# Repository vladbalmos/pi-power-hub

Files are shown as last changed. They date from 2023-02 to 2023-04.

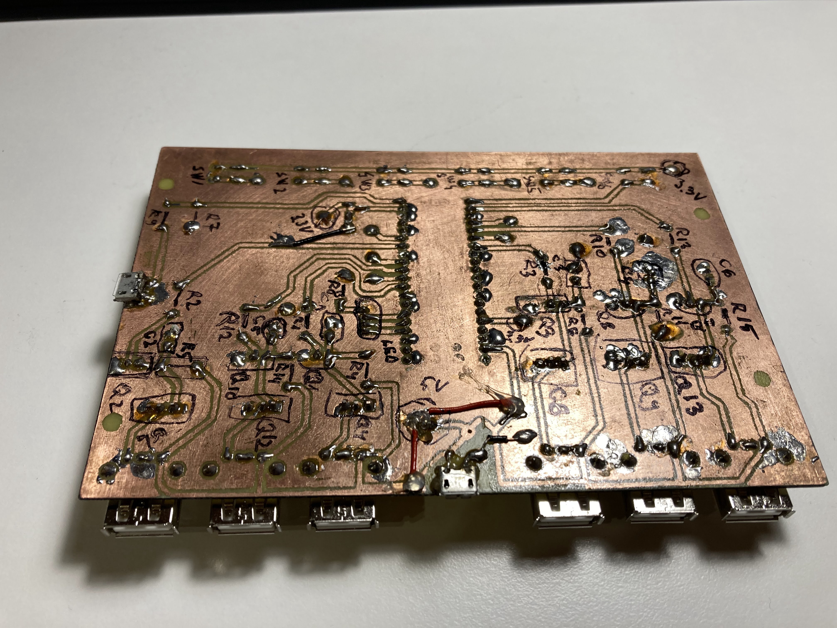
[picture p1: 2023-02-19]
hw/board_back.jpg

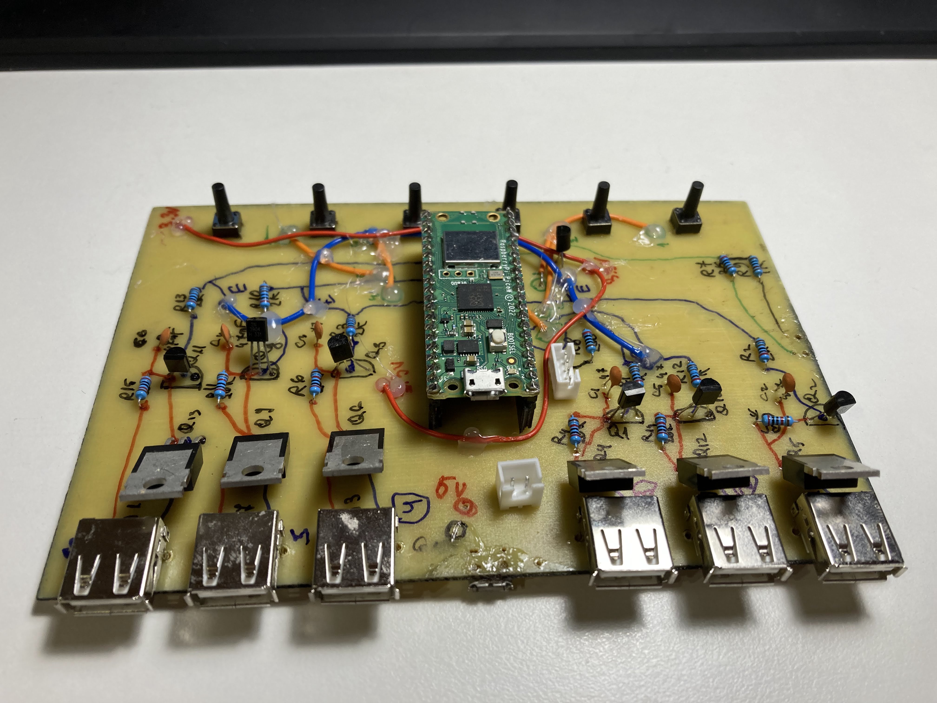
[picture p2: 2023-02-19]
hw/board_front.jpg

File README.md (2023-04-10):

# System requirements
* micropython
* ampy
* minicom (optional)

# Development
Build micropython:

    cd [mycropython-dir]
    make -C mpy-cross

    cd [mycropython-dir]/ports/rp2
    make -j4 BOARD=PICO_W submodules
    make -j4 BOARD=PICO_W clean
    make -j4 BOARD=PICO_W
    
Set wifi SSID & password:

    cp wifi_credentials.template src/wifi_credentials.py
    # edit src/wifi_credentials.py and add SSID & SSID password

Init:

    pip3 install -r requirements.txt
    ./setup.sh
    make build
    
Run:

    make run
    
Clean

    make clean
    
Upload

    make upload
    
Build

    make build

# Topics
* vb/devices/power/pihub/request
    - device subscribes for state change requests
* vb/devices/power/pihub/response
    - device publishes state changes
* vb/devices/request
    - device subscribes for registration requests
* vb/devices/response
    - device publishes device registration data

# Status LED meanings:
* red
    - board initializing
* blue
    - connecting to mqtt server
* green
    - connected to mqtt server
* yellow
    - lost connection to mqtt

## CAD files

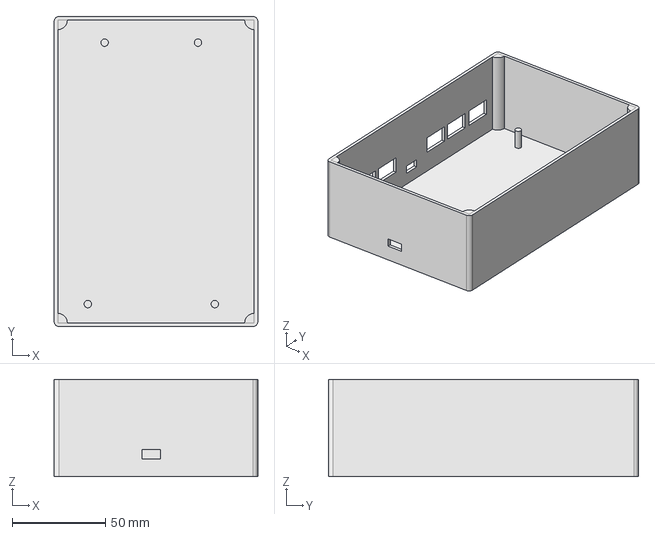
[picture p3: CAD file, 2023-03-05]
hw/enclosure/enclosure.FCStd
109.0 x 166.0 x 52.0 mm

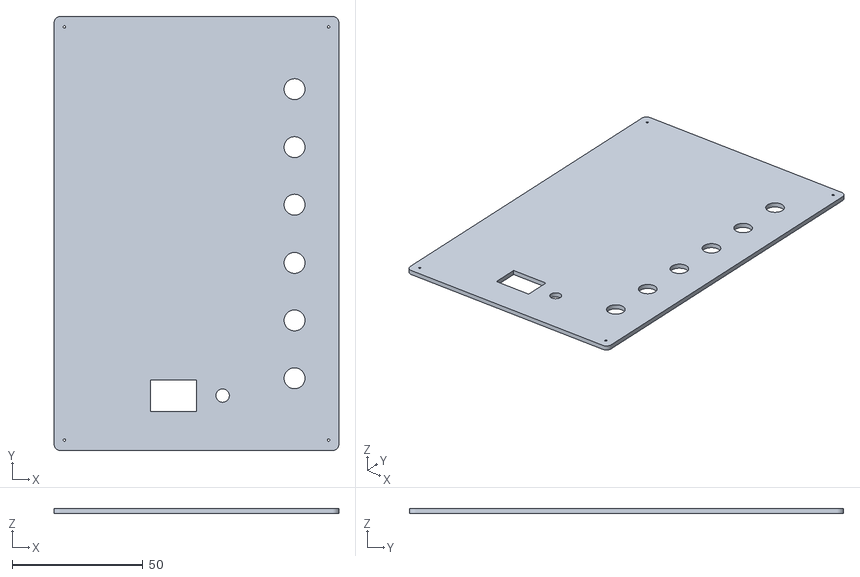
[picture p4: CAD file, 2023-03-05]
hw/enclosure/lid-EnclosureLidBody.stl
109.0 x 166.0 x 2.00

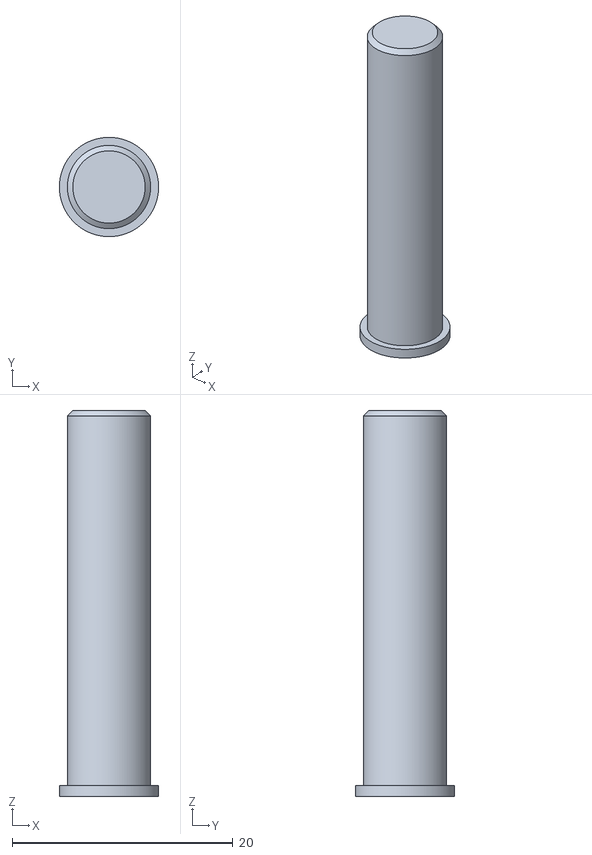
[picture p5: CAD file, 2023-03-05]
hw/enclosure/button-Body.stl
9.00 x 9.00 x 35.0

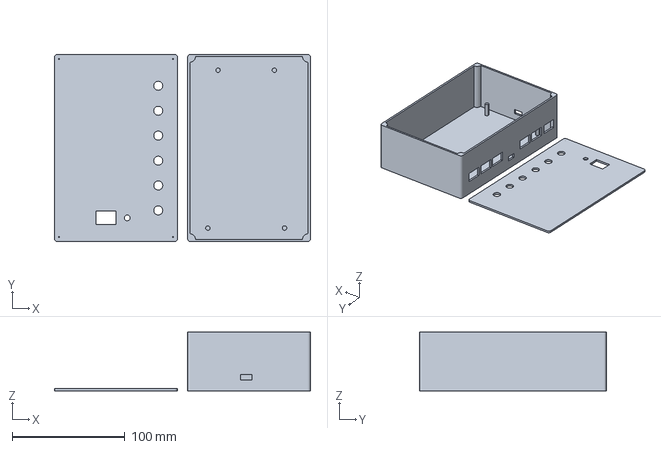
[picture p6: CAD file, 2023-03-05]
hw/enclosure/case.3mf
227.0 x 166.0 x 52.0 mm

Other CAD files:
hw/enclosure/assembled.FCStd
hw/enclosure/body.3mf
hw/enclosure/button.FCStd
hw/enclosure/enclosure-EnclosureBody.stl
hw/enclosure/lid.FCStd
hw/enclosure/button.3mf
hw/enclosure/case.stl
hw/enclosure/lid.3mf

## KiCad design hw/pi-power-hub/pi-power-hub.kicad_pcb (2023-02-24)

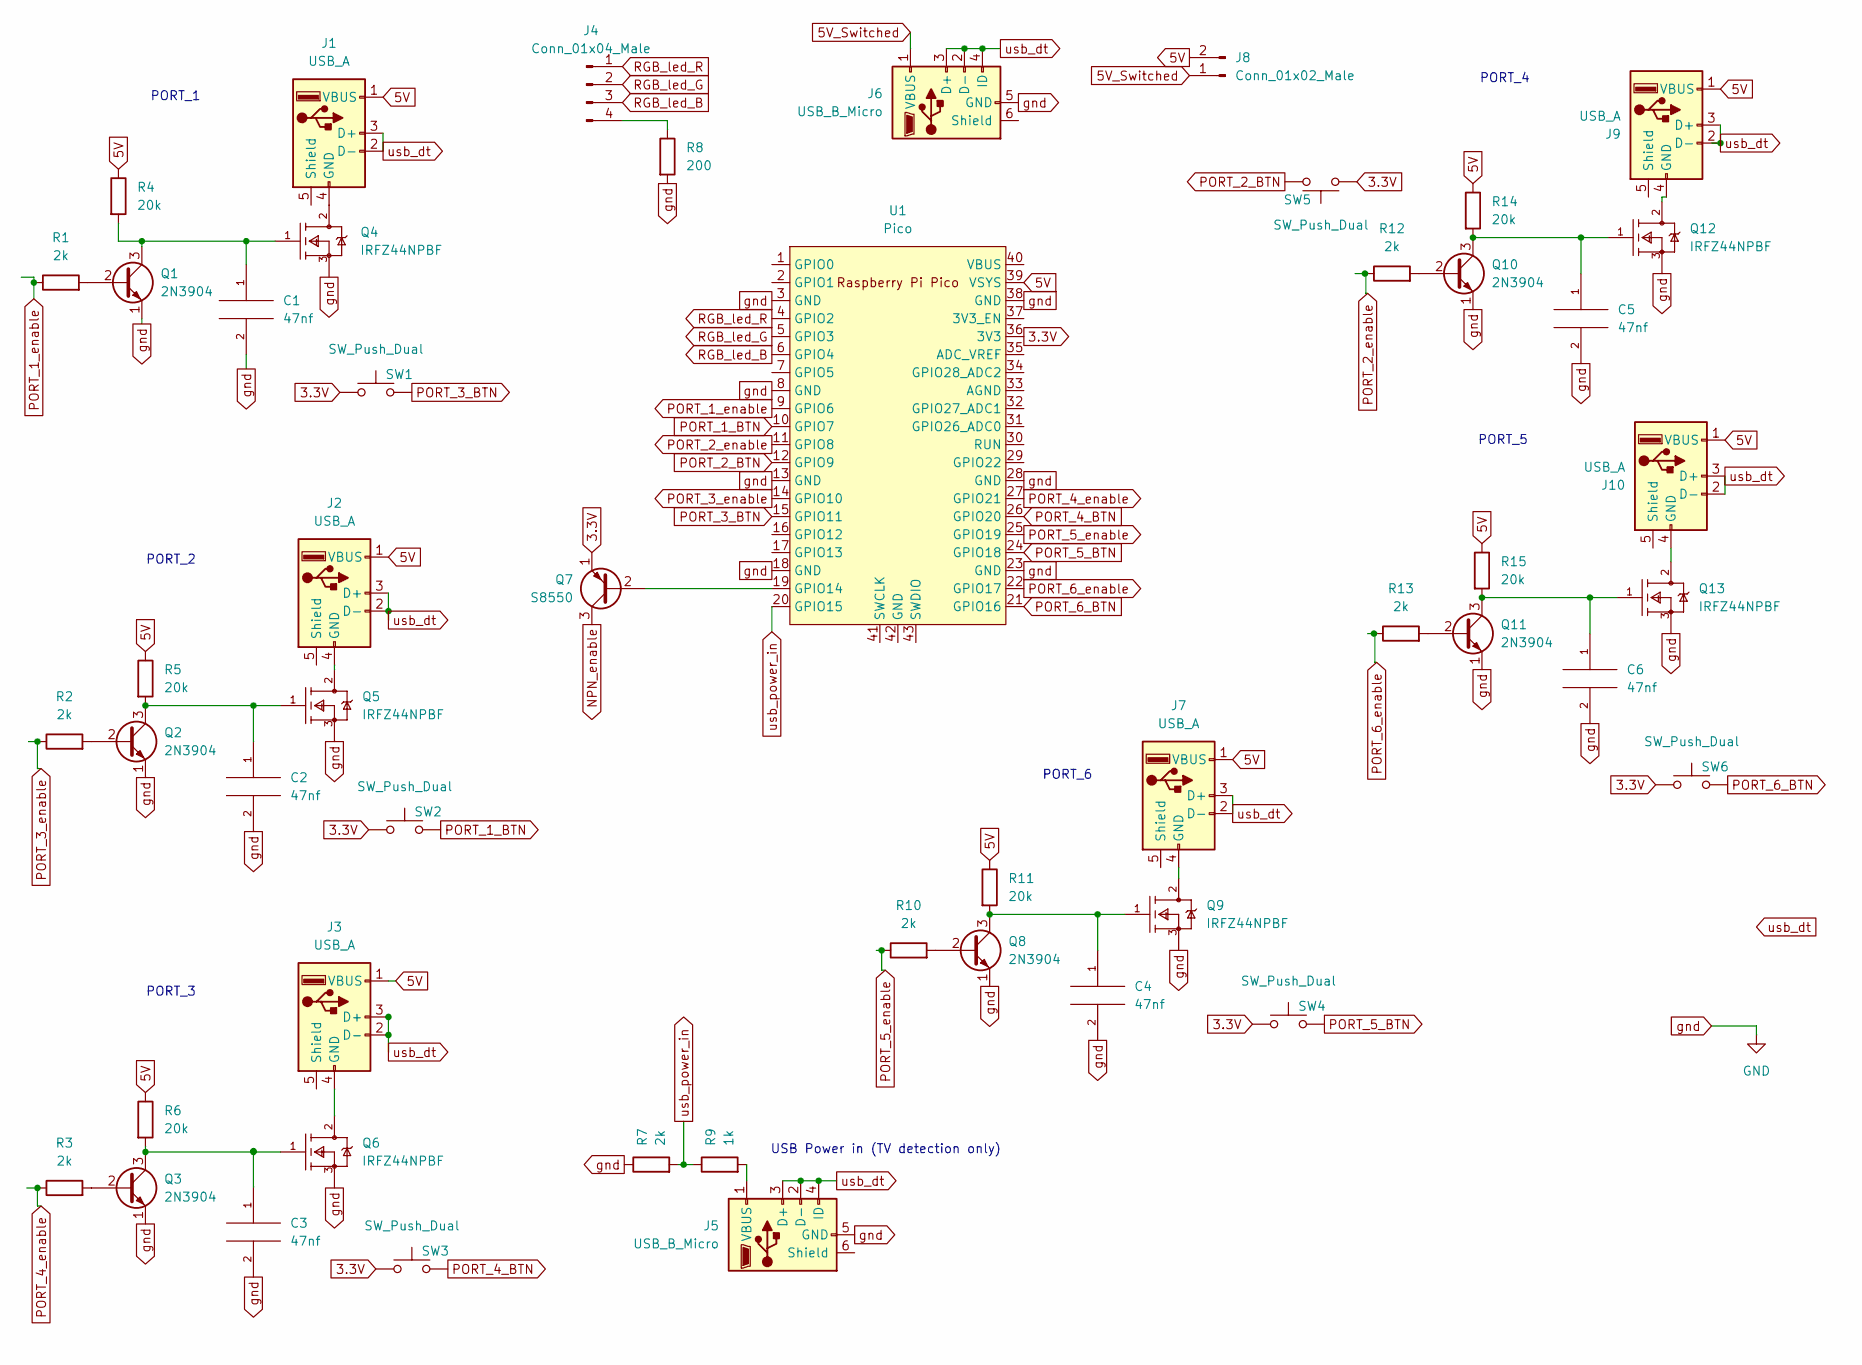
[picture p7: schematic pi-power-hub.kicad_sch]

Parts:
C1, C2, C3, C4, C5, C6: 47nf; C_Disc_D3.8mm_W2.6mm_P2.50mm
J1, J2, J3, J7, J9, J10: USB_A; USB_A_Molex_67643_Horizontal
J4: Conn_01x04_Male; JST_PH_B4B-PH-K_1x04_P2.00mm_Vertical
J5, J6: USB_B_Micro; USB_Micro-B_Amphenol_10103594-0001LF_Horizontal
J8: Conn_01x02_Male; JST_XH_B2B-XH-A_1x02_P2.50mm_Vertical
Q1, Q2, Q3, Q8, Q10, Q11: 2N3904; TO-92_Inline
Q4, Q5, Q6, Q9, Q12, Q13: IRFZ44NPBF; Infineon_Technologies_AG-IRFZ44NPBF-0; mouser part number 942-IRFZ44NPBF; digikey description N-Channel 55V 49A (Tc) 94W (Tc) Through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
Q7: S8550; TO-92_Inline
R1, R2, R3, R7, R10, R12, R13: 2k; R_Axial_DIN0207_L6.3mm_D2.5mm_P7.62mm_Horizontal
R4, R5, R6, R11, R14, R15: 20k; R_Axial_DIN0207_L6.3mm_D2.5mm_P7.62mm_Horizontal
R8: 200; R_Axial_DIN0207_L6.3mm_D2.5mm_P7.62mm_Horizontal
R9: 1k; R_Axial_DIN0207_L6.3mm_D2.5mm_P7.62mm_Horizontal
SW1, SW2, SW3, SW4, SW5, SW6: SW_Push_Dual; SW_PUSH_6mm_H8.5mm
U1: Pico; RPi_Pico_SMD_TH

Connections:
3.3V: Q7.1 (E), SW1.1, SW2.1, SW3.1, SW4.1, SW5.1, SW6.1, U1.36 (3V3)
5V: J1.1 (VBUS), J2.1 (VBUS), J3.1 (VBUS), J7.1 (VBUS), J8.2, J9.1 (VBUS), J10.1 (VBUS), R4.1, R5.1, R6.1, R11.1, R14.1, R15.1, U1.39 (VSYS); also elsewhere on the board
5V_Switched: J6.1 (VBUS), J8.1
NPN_enable: Q7.3 (C)
unnamed: C1.1, Q1.3 (C), Q4.1 (GATE), R4.2
unnamed: C2.1, Q2.3 (C), Q5.1 (GATE), R5.2
unnamed: C3.1, Q3.3 (C), Q6.1 (GATE), R6.2
unnamed: C4.1, Q8.3 (C), Q9.1 (GATE), R11.2
unnamed: C5.1, Q10.3 (C), Q12.1 (GATE), R14.2
unnamed: C6.1, Q11.3 (C), Q13.1 (GATE), R15.2
unnamed: J1.4 (GND), Q4.2 (DRAIN)
unnamed: J2.4 (GND), Q5.2 (DRAIN)
unnamed: J3.4 (GND), Q6.2 (DRAIN)
unnamed: J4.4, R8.1
unnamed: J5.1 (VBUS), R9.2
unnamed: J7.4 (GND), Q9.2 (DRAIN)
unnamed: J9.4 (GND), Q12.2 (DRAIN)
unnamed: J10.4 (GND), Q13.2 (DRAIN)
unnamed: Q1.2 (B), R1.2
unnamed: Q2.2 (B), R2.2
unnamed: Q3.2 (B), R3.2
unnamed: Q7.2 (B), U1.19 (GPIO14)
unnamed: Q8.2 (B), R10.2
unnamed: Q10.2 (B), R12.2
unnamed: Q11.2 (B), R13.2
PORT_1_BTN: SW2.2, U1.10 (GPIO7)
PORT_1_enable: R1.1, U1.9 (GPIO6)
PORT_2_BTN: SW5.2, U1.12 (GPIO9)
PORT_2_enable: R12.1, U1.11 (GPIO8)
PORT_3_BTN: SW1.2, U1.15 (GPIO11)
PORT_3_enable: R2.1, U1.14 (GPIO10)
PORT_4_BTN: SW3.2, U1.26 (GPIO20)
PORT_4_enable: R3.1, U1.27 (GPIO21)
PORT_5_BTN: SW4.2, U1.24 (GPIO18)
PORT_5_enable: R10.1, U1.25 (GPIO19)
PORT_6_BTN: SW6.2, U1.21 (GPIO16)
PORT_6_enable: R13.1, U1.22 (GPIO17)
RGB_led_B: J4.3, U1.6 (GPIO4)
RGB_led_G: J4.2, U1.5 (GPIO3)
RGB_led_R: J4.1, U1.4 (GPIO2)
gnd: C1.2, C2.2, C3.2, C4.2, C5.2, C6.2, J5.5 (GND), J6.5 (GND), Q1.1 (E), Q2.1 (E), Q3.1 (E), Q4.3 (SOURCE), Q5.3 (SOURCE), Q6.3 (SOURCE), Q8.1 (E), Q9.3 (SOURCE), Q10.1 (E), Q11.1 (E), Q12.3 (SOURCE), Q13.3 (SOURCE), R7.1, R8.2, U1.3 (GND), U1.8 (GND), U1.13 (GND), U1.18 (GND), U1.23 (GND), U1.28 (GND), U1.38 (GND)
usb_dt: J1.2 (D-), J1.3 (D+), J2.2 (D-), J2.3 (D+), J3.2 (D-), J3.3 (D+), J5.2 (D-), J5.3 (D+), J5.4 (ID), J6.2 (D-), J6.3 (D+), J6.4 (ID), J7.2 (D-), J7.3 (D+), J9.2 (D-), J9.3 (D+), J10.2 (D-), J10.3 (D+)
usb_power_in: R7.2, R9.1, U1.20 (GPIO15)

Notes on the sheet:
PORT_2
PORT_3
PORT_5
USB Power in (TV detection only)
PORT_4
PORT_1
PORT_6

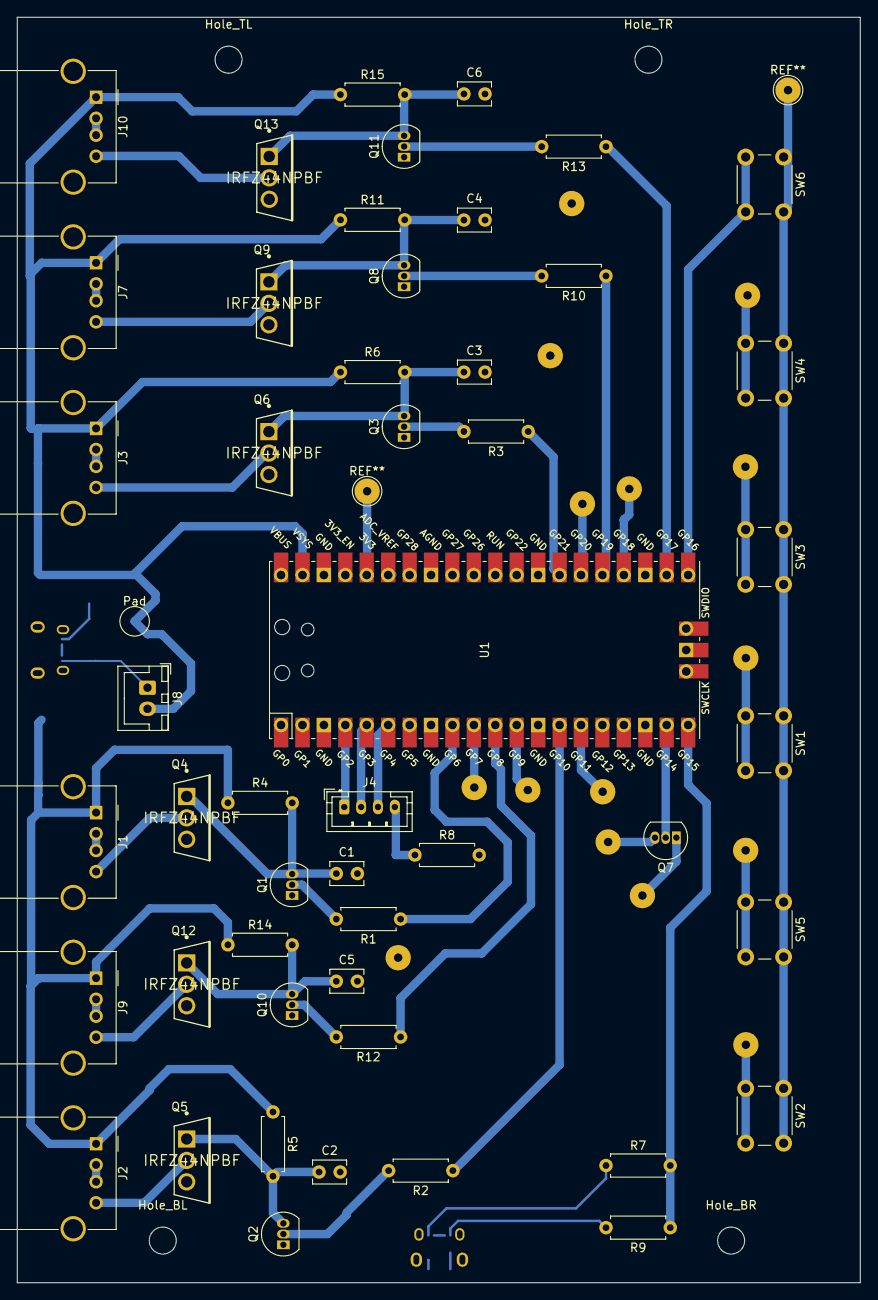
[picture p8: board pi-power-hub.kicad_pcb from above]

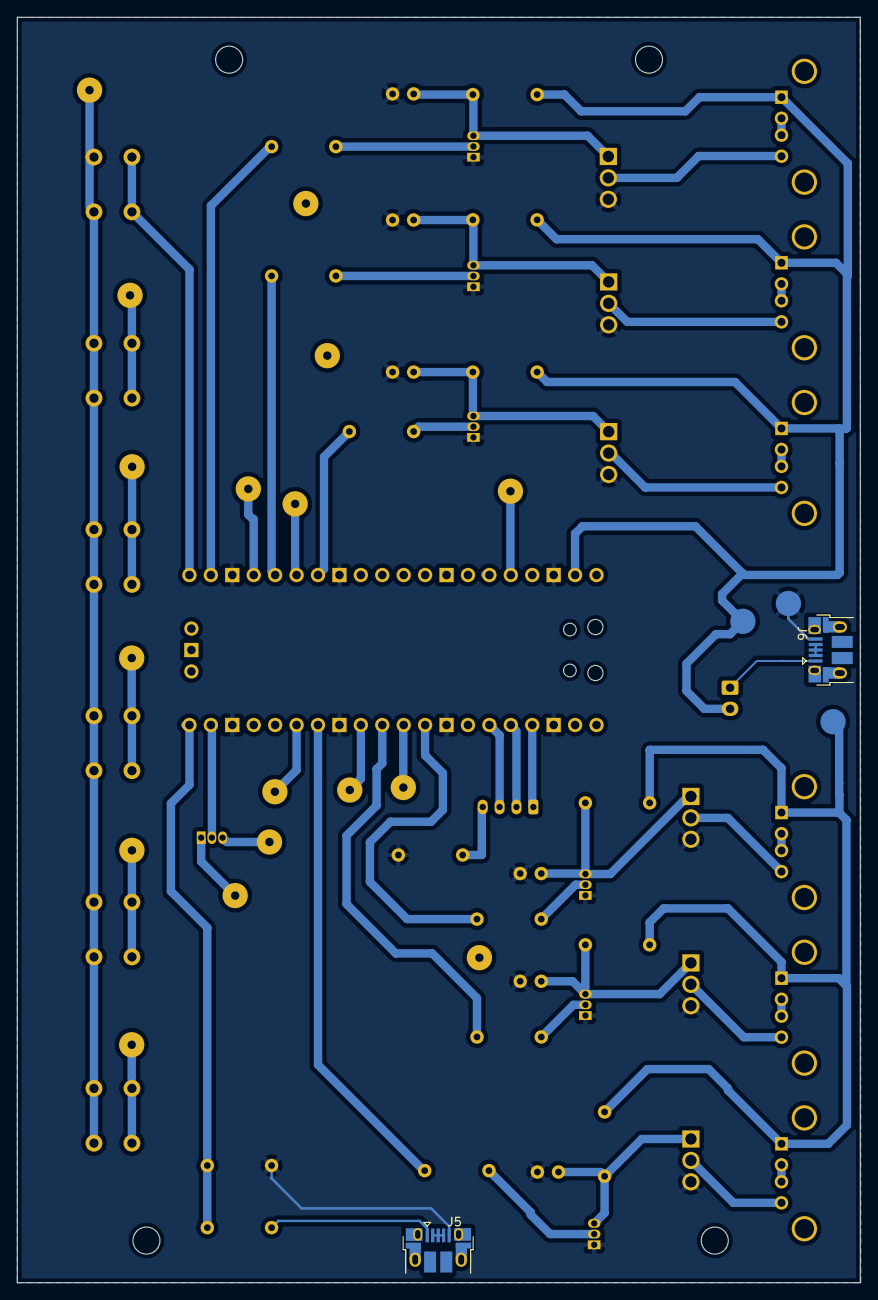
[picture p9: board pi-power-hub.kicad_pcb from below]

Board: 2 copper layers, 99.9 x 150.0 mm, 56 parts (2 on the bottom side), 42 nets.

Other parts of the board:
Hole_BL: MountingHole_3.2mm_M3
Hole_BR: MountingHole_3.2mm_M3
Hole_TL: MountingHole_3.2mm_M3
Hole_TR: MountingHole_3.2mm_M3
Pad: TestPoint_Pad_D3.0mm

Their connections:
5V: Pad.1; also elsewhere on the board

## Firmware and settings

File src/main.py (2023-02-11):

import device
import machine
import uasyncio as asyncio
from queue import Queue
import net

def valid_state_update_request(msg):
    if 'request' not in msg:
        return False
        
    if msg['request'] != 'state-update':
        return False

    if 'payload' not in msg:
        return False
        
    payload = msg['payload']
    
    if 'deviceId' not in payload or 'featureId' not in payload:
        return False
        
    if payload['deviceId'] != device.id:
        return False
        
    return device.has_feature(payload['featureId'])
        
async def main():
    led = machine.Pin('LED', machine.Pin.OUT)

    msg_queue = Queue(32)
    device_queue = Queue(32)
    net_state_queue = Queue(32)

    device_registration = device.init_state(device_queue)
    
    print("Initializing connection")
    asyncio.create_task(net.init(device_registration, msg_queue, net_state_queue))
    asyncio.create_task(device.poll_inputs())
    
    while True:
        led.toggle()
        if not msg_queue.empty():
            msg = msg_queue.get_nowait()
            if valid_state_update_request(msg):
                updates = device.update(msg['payload'])
                for (feature_id, new_state) in updates:
                    if feature_id is not None:
                        net.queue_state_publishing(feature_id, new_state)
                        
        while not net_state_queue.empty():
            net_state = net_state_queue.get_nowait()
            if net_state == 'connecting':
                device.led_color('blue')
            elif net_state == 'up':
                device.led_color('green')
            else:
                device.led_color('yellow')
            
        while not device_queue.empty():
            led.toggle()
            feature_id, new_state = device_queue.get_nowait()
            net.queue_state_publishing(feature_id, new_state)
            
        await asyncio.sleep_ms(50)
        
asyncio.run(main())
asyncio.new_event_loop()

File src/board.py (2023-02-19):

from machine import Pin
from led_color import LEDColor

LED_R_PIN = 2
LED_G_PIN = 3
LED_B_PIN = 4

PORT_0 = 10
PORT_1 = 8
PORT_2 = 6
PORT_3 = 21
PORT_4 = 19
PORT_5 = 17

INPUT_0 = 11
INPUT_1 = 9
INPUT_2 = 7
INPUT_3 = 20
INPUT_4 = 18
INPUT_5 = 16

READY_PIN = 14
USB_IN = 15

output_pins = [PORT_0, PORT_1, PORT_2, PORT_3, PORT_4, PORT_5]
input_pins = [INPUT_0, INPUT_1, INPUT_2, INPUT_3, INPUT_4, INPUT_5, USB_IN]
input_pins_values = []

output_ports = []
input_ports = []

led_r = LEDColor(Pin(LED_R_PIN), 255, 128)
led_g = LEDColor(Pin(LED_G_PIN), 0, 64)
led_b = LEDColor(Pin(LED_B_PIN), 0, 64)

rgb_led_color = 'red'
rgb_led = [led_r, led_g, led_b]

# While the board is initializing, this pin is low by default, thus sourcing current to all output port transistor
# drivers - via a PNP transitor, preventing power flickering during board initialization
ready_pin = Pin(READY_PIN, Pin.OUT)
ready_pin.value(1)

for p in output_pins:
    pin = Pin(p, Pin.OUT)
    pin.on()
    output_ports.append(pin)
    
for p in input_pins:
    pin = Pin(p, Pin.IN, Pin.PULL_DOWN)
    value = pin.value()
    
    input_pins_values.append(value)
    input_ports.append(pin)

def restore_state(state):
    always_on_ports = list(filter(lambda item: item['id'] == 'always_on_list', state))

    if len(always_on_ports):
        always_on_ports = always_on_ports.pop()
        if 'value' in always_on_ports:
            always_on_ports = always_on_ports['value']
        else:
            always_on_ports = []
    else:
        always_on_ports = []

    for feature in state:
        if 'port_' in feature['id']:
            if feature['id'] in always_on_ports:
                value = 1
            elif 'value' in feature:
                value = int(feature['value'])
            else:
                value = int(feature['schema']['default'])

            port_index = int(feature['id'][5:])

            # Ports are active low
            output_ports[port_index].value(int(not value))
            
def get_changed_inputs():
    index = 0
    changes = []
    for p in input_ports:
        value = p.value()
        if index == len(input_pins) - 1:
            key = 'usb_in'
        else:
            key = f'port_{index}'

        if value != input_pins_values[index]:
            changes.append((key, value))
            input_pins_values[index] = value
        index += 1
    return changes

def update(port_id, state):
    if 'port_' not in port_id:
        return
    index = int(port_id[5:])
    output_ports[index].value(int(not state))
    
def led_color(color):
    global rgb_led, rgb_led_color
    
    colors = [0, 0, 0]
    if color == 'red':
        colors = [255, 0, 0]
    elif color == 'blue':
        colors = [0, 0, 255]
    elif color == 'yellow':
        colors = [255, 128, 0]
    elif color == 'green':
        colors = [0, 255, 0]
    else:
        # any other color names turn the LED off
        pass

    rgb_led_color = color
        
    for i in range(0, 3):
        rgb_led[i].value(colors[i])

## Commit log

2023-01-25 Update devices features schema
2023-02-11 Add status RGB led
    [pi-power-hub.kicad_pcb, pi-power-hub.kicad_sch]
2023-02-11 Fine tune RGB status led
2023-02-19 Change output pins order
    [pi-power-hub.kicad_pcb, pi-power-hub.kicad_sch]
2023-02-19 Improve readme and add board pics
2023-02-24 Add 3d model and slicer file
    [assembled.FCStd, case.3mf, case.stl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]
2023-02-24 Update 3d model
    [assembled.FCStd, enclosure.FCStd, lid.FCStd]
2023-03-03 Update 3d print settings
    [assembled.FCStd, case.3mf, case.stl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]
2023-03-05 Update models
    [assembled.FCStd, body.3mf, button-Body.stl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]
